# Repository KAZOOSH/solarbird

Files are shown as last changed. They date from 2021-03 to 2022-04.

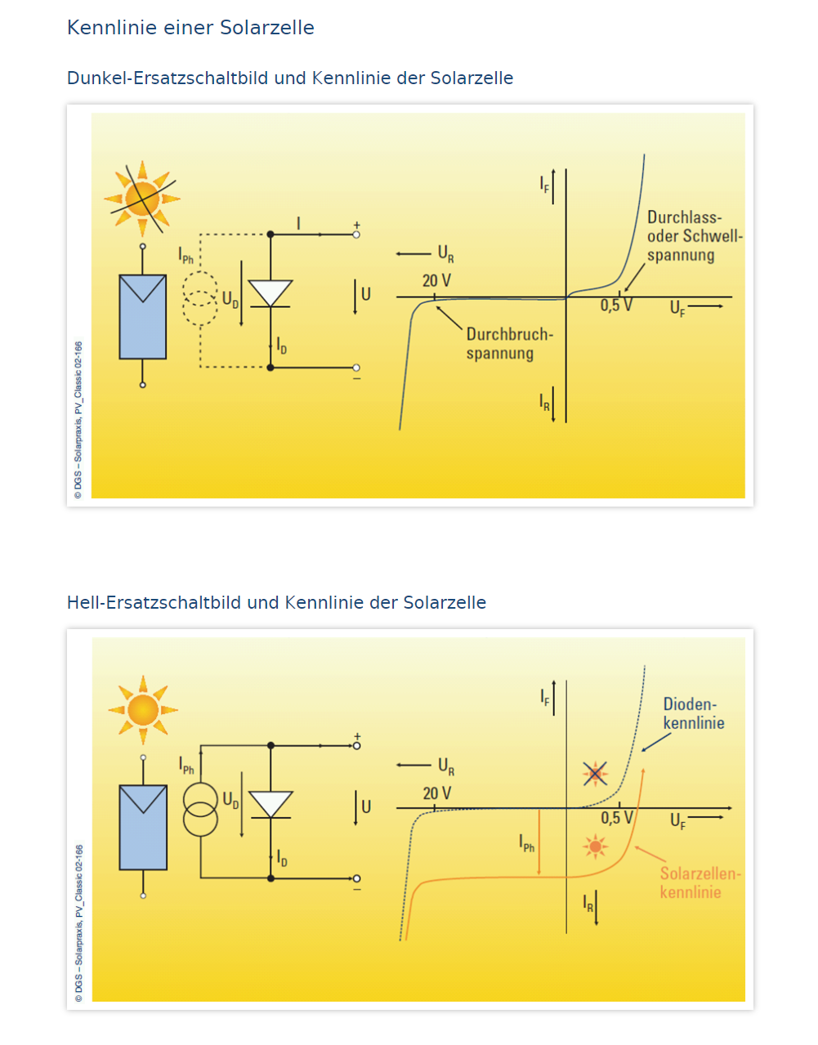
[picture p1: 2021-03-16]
material/Solarzelle_helldunkelkennlinie.png

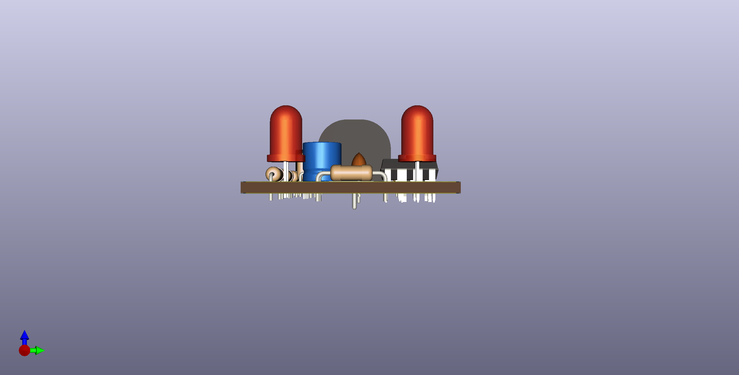
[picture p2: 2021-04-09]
pcb/Solaranimal_current pcb/board_t.png

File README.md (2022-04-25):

# Solarbird
Chirping birds with an ATtiny heart.

## How to flash SolarbirdTiny.ino with Arduino IDE

- Get an AVR ISP programmer or a spare Arduino and follow [these instructions](https://create.arduino.cc/projecthub/arjun/programming-attiny85-with-arduino-uno-afb829)
- Under Tools, select board “ATtiny25/45/85”, processor “ATtiny85”, and clock “Internal 8 MHz”
- Again under Tools, click Burn Bootloader (won't actually flash the Arduino bootloader but just set the fuses)
- Optional: change the code to include the bird voice of your choice (see following section)
- Flash the Arduino program as usual by clicking the Upload button

## How to change the bird's voice

At the time of writing, we have an imitation of a blackbird, a chiffchaff, a titmouse and a wren. Check the folder [voices](SolarbirdTiny/voices/) for all available bird voices.

In [SolarbirdTiny.ino near line 23](SolarbirdTiny/SolarbirdTiny.ino#L23), find the lines which include the bird voice and create a _Bird_ instance from it:
```c++
#include "voices/blackbird.h"
Blackbird Bird;
```

Change the name of the included file on the first line to the one of your liking. The code follows the convention that the class name (first word on the second line) is the capitalized version of the filename, i.e., the file `chiffchaff.h` contains the class `Chiffchaff`. After changing both lines, you're ready to upload the new voice to the ATtiny.

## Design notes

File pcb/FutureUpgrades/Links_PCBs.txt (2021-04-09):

pcb manufacturer tested with sharing options:

https://aisler.net/p/BBQTFBOA #####Germany Board V1.3 (add PROTO, remove 3.hole, add 2resistors for Akku state and mic bias)
https://oshpark.com/shared_projects/yvOFolXe #####Canada Board V1.31 ("After Dark" design)

pcb manufacturer also tested:
https://www.pcbway.com/ #####China
https://jlcpcb.com/ #####China

pcb manufacturer today not testet:
https://www.pcb-supermarkt.de/ #####Germany

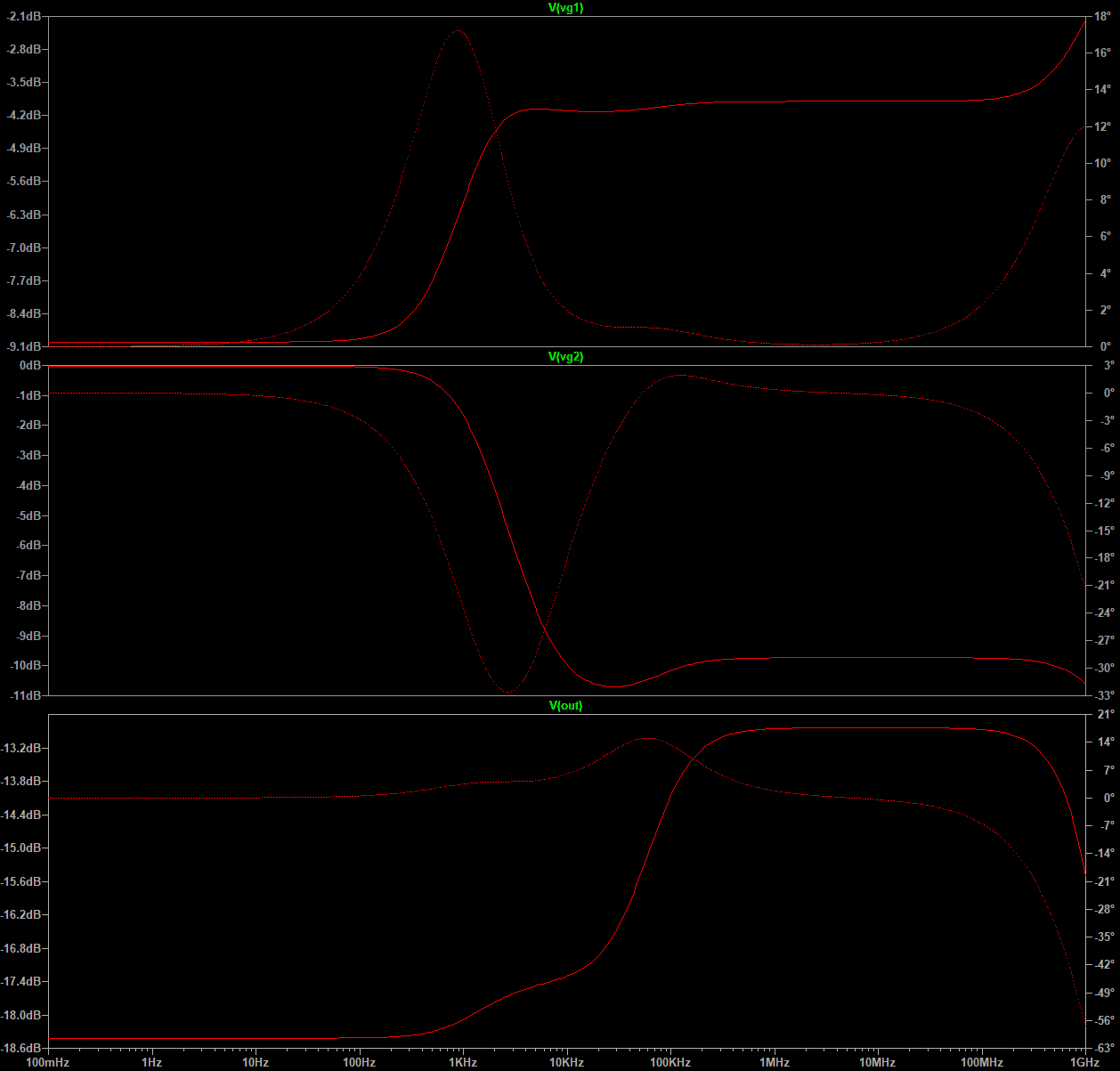
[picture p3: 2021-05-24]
circuit/spice/errorampAC.png

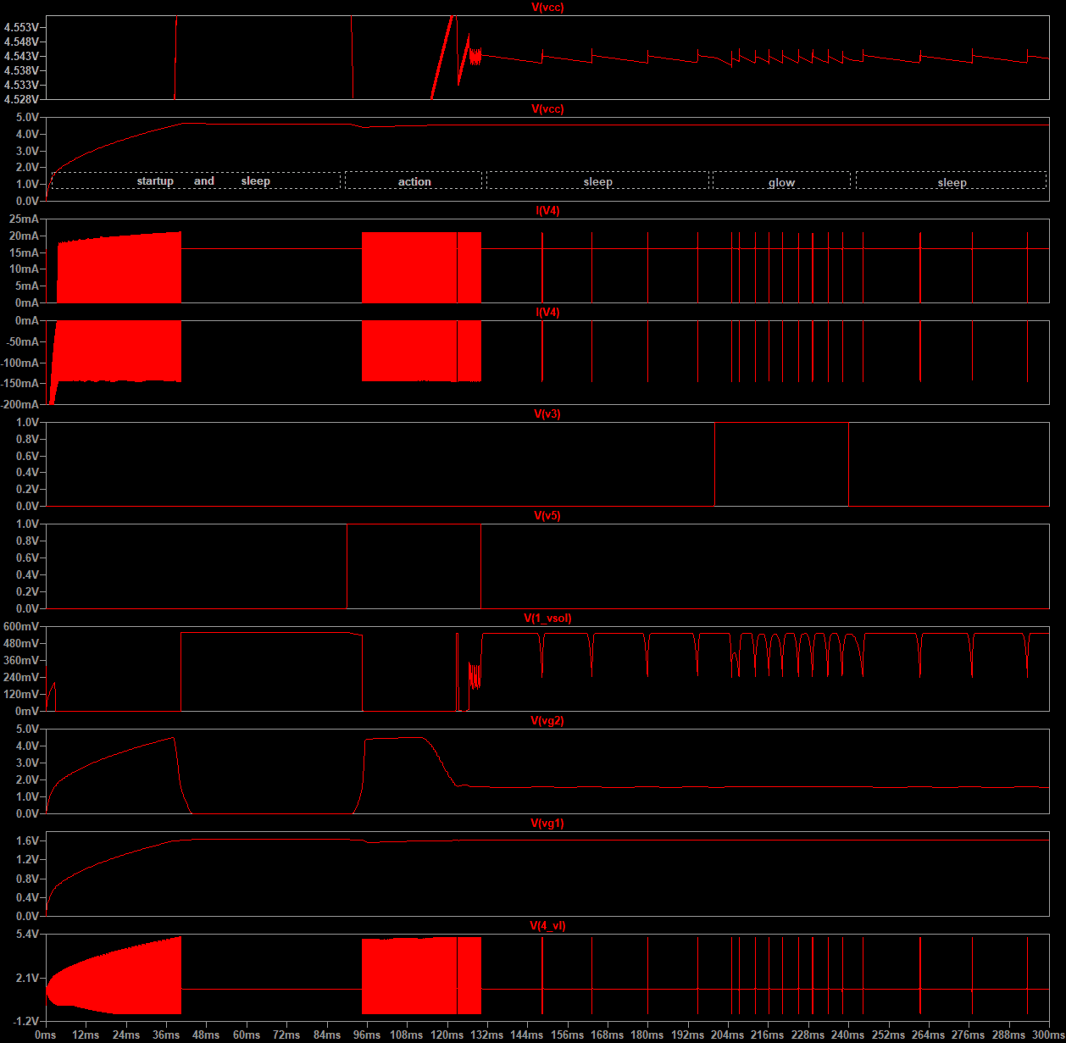
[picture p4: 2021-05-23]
circuit/spice/signals.png

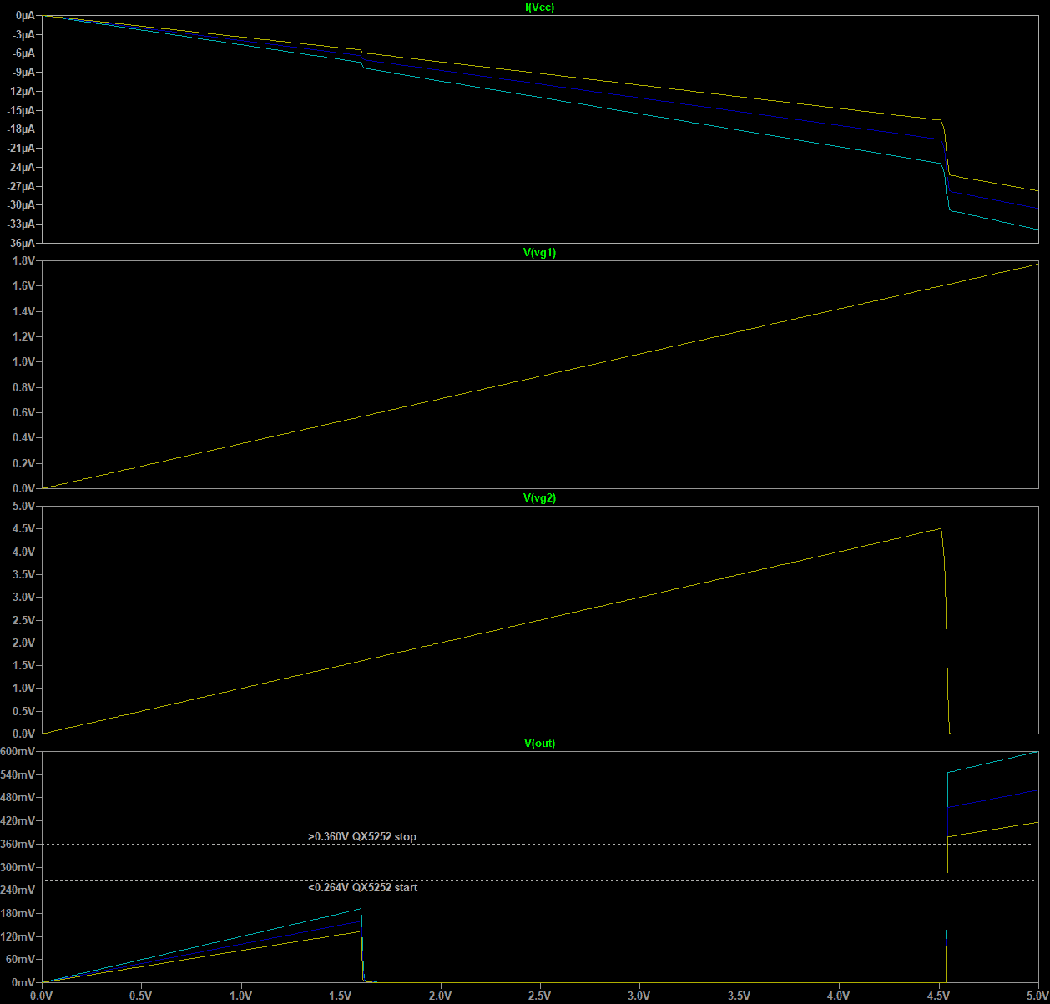
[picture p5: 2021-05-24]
circuit/spice/errorampDC.png

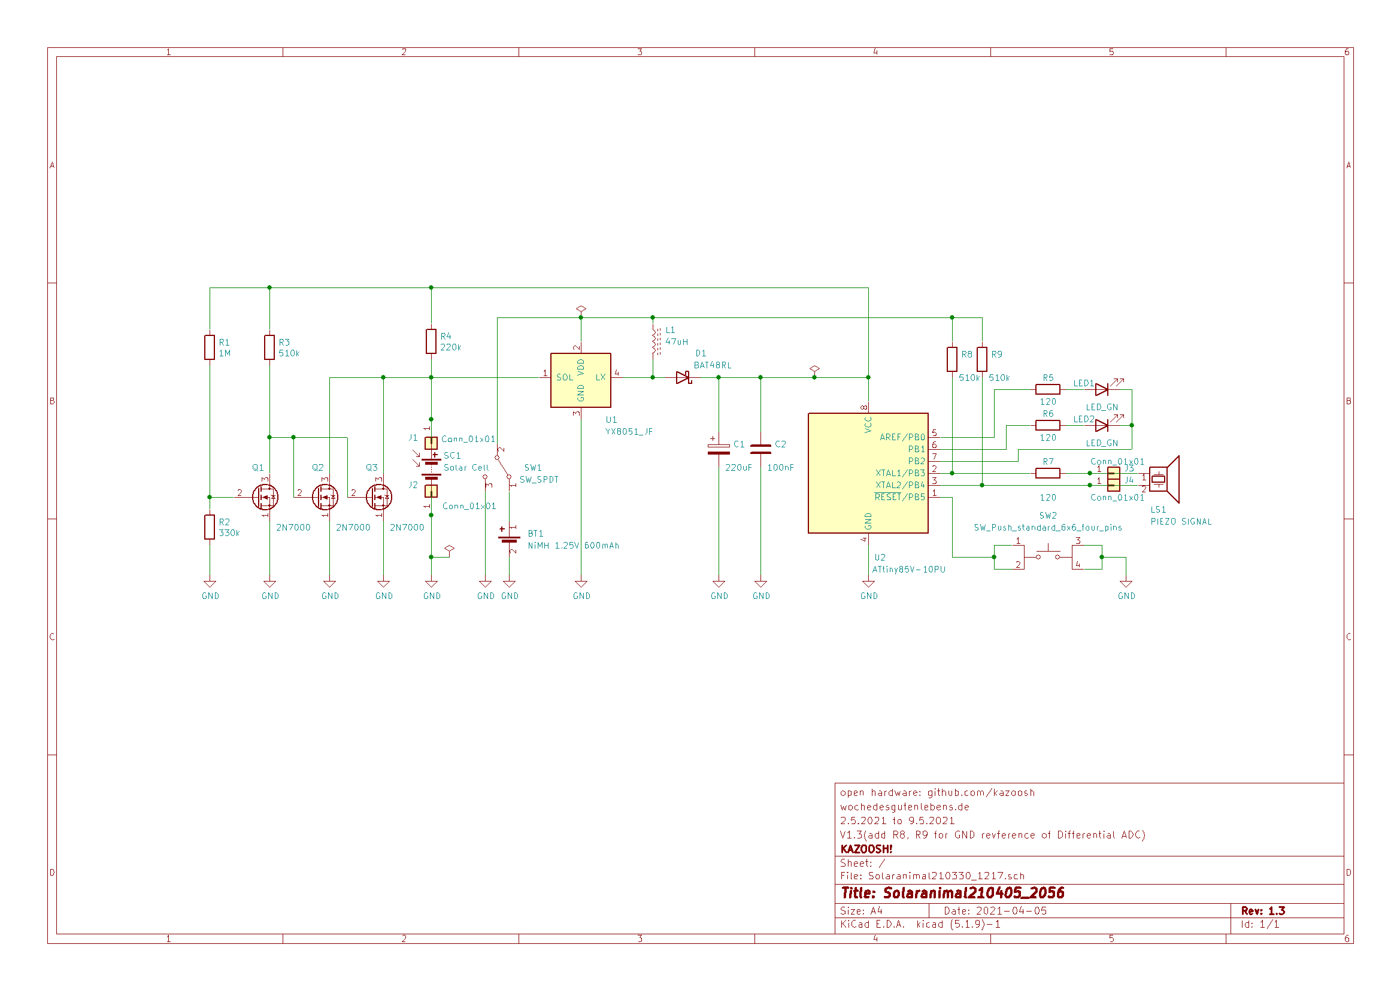
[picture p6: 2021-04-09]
pcb/FutureUpgrades/circuit.png

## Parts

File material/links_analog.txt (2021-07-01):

https://www.researchgate.net/publication/265036087_Analog_Front-End_Circuitry_in_Piezoelectric_and_Microphone_Detection_of_Photoacoustic_Signals
https://ww1.microchip.com/downloads/en/DeviceDoc/2N7000-N-Channel-Enhancement-Mode-Vertical-DMOS-FET-Data-Sheet-20005695A.pdf
https://simplifier.neocities.org/joule.html
https://www.tme.eu/de/details/ld-bzpn-2312/elektromagnetische-signalgeber-ohne-gen/loudity/ #####Piezo bei TME
https://www.onsemi.com/pdf/datasheet/mmbf170-d.pdf ##### BS170 Datasheed
http://schmidt-walter-schaltnetzteile.de/smps/smps.html #####Dimensionierung von Schaltnetzteilen
https://i.pinimg.com/originals/ae/01/0a/ae010a932937a33a02e720dccd400e55.jpg #####Farbcodes für Widerstände

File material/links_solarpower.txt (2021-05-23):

https://www.sciencetronics.com/greenphotons/?p=155
http://solarbotics.net/library/datasheets/sunceram.pdf
http://markbeck.de/elektronik.html
https://www.slideserve.com/urielle-clayton/photovoltaik
https://skootsone.yolasite.com/solar-led.php
http://www.elektronik-labor.de/Notizen/Solarlampen.html
https://www.elektronik-labor.de/Notizen/LEDwandler.html

https://datasheetspdf.com/datasheet/YX8051.html
https://oberguru.net/elektronik/led/step-up-wandler/qx5252/qx5252.html

https://www.electronicdeveloper.de/InduktivitaetSpeicherSNT.aspx ####Berechnung von Speicherdrosseln
https://www.tdk-electronics.tdk.com/download/528882/71e02c7b9384de1331b3f625ce4b2123/pdf-n87.pdf ####Kernmaterial N87
https://www.tdk-electronics.tdk.com/inf/80/db/fer/r_10_0_6_00_4_00.pdf ####Toroid core 10x6x4

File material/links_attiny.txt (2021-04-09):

https://ww1.microchip.com/downloads/en/DeviceDoc/Atmel-2586-AVR-8-bit-Microcontroller-ATtiny25-ATtiny45-ATtiny85_Datasheet.pdf
https://www.monsterli.ch/blog/elektronik/mikrocontroller/attiny25-attiny45-attiny85-sammelsurium/
http://www.technoblogy.com/show?QVN
http://www.technoblogy.com/show?QBB
http://www.technoblogy.com/show?ZU7
http://elm-chan.org/works/sd8p/report.html
http://elm-chan.org/works/sd20p/report.html
ADC App notes:
http://ww1.microchip.com/downloads/en/AppNotes/doc8003.pdf
http://ww1.microchip.com/downloads/en/Appnotes/atmel-8456-8-and-32-bit-avr-microcontrollers-avr127-understanding-adc-parameters_application-note.pdf
http://ww1.microchip.com/downloads/en/Appnotes/Atmel-2559-Characterization-and-Calibration-of-the-ADC-on-an-AVR_ApplicationNote_AVR120.pdf
https://microchipdeveloper.com/8avr:adcdiff
https://blog.podkalicki.com/100-projects-on-attiny13/
https://www.instructables.com/ElectronicKittyEars-Headset-DIY/ #####DIY Programmer for Kittys

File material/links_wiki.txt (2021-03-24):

210323:
https://docs.google.com/spreadsheets/d/1iGpreHylvdMuwipeQVSpeXQ6AU2KrBsxj3lGD7Qvc1k/edit?usp=sharing

https://www.youtube.com/watch?v=KNeW3BZsALQ

https://raw.githubusercontent.com/badgeek/svg2shenzhen/master/doc/resources/showcase.jpeg

https://pcbshopper.com/

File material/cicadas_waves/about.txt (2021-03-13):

timecode: xxx:xx:ms
stereo in 1
sampling rate 44100Hz

source: Der Sound des Sommers... .mp3

the envelope of cicadas sounds is about 110ms to 160ms
sound is about 50% of the envelope
base frequency is about 5500Hz
there are 3ms ripples in the amplitude of base frequency

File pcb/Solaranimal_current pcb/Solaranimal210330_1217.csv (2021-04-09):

Id | Designator | Package | Quantity | Designation | Supplier and ref
1 | Q2 | TO-92_Inline_Wide | 1 | ZVN4206AVSTZ
2 | G*** | Kazoosh!-Logo | 1 | LOGO
3 | M3 | MountingHole_3.2mm_M3_Pad_TopBottom | 1 | MountingHole_3.2mm_M3_Pad_TopBottom
4 | SW2 | SW_PUSH_6mm_H5mm_4pin | 1 | SW_Push_standard_6x6_four_pins
5 | U2 | DIP-8_W7.62mm | 1 | ATtiny85V-10PU
6 | U1 | R_Array_SIP4 | 1 | YX8051_JF
7 | SW1 | SW_Slide_1P2T_CK_OS102011MS2Q | 1 | SW_SPDT
8 | R7,R6,R5 | R_Axial_DIN0207_L6.3mm_D2.5mm_P10.16mm_Horizontal | 3 | 120
9 | R4 | R_Axial_DIN0207_L6.3mm_D2.5mm_P10.16mm_Horizontal | 1 | 220k
10 | R3 | R_Axial_DIN0207_L6.3mm_D2.5mm_P10.16mm_Horizontal | 1 | 510k
11 | R2 | R_Axial_DIN0207_L6.3mm_D2.5mm_P10.16mm_Horizontal | 1 | 330k
12 | R1 | R_Axial_DIN0207_L6.3mm_D2.5mm_P10.16mm_Horizontal | 1 | 1M
13 | Q1 | TO-92_Inline_Wide | 1 | 2N7000
14 | LED2,LED1 | LED_D5.0mm | 2 | LED_GN
15 | L1 | R_Axial_DIN0207_L6.3mm_D2.5mm_P10.16mm_Horizontal | 1 | 47uH
16 | J4,J3,J2,J1 | SolderWire-0.5sqmm_1x01_D0.9mm_OD2.1mm_Relief | 4 | Conn_01x01
17 | D1 | D_DO-35_SOD27_P10.16mm_Horizontal | 1 | BAT48RL
18 | C2 | C_Disc_D4.7mm_W2.5mm_P5.00mm | 1 | 100nF
19 | C1 | CP_Radial_D6.3mm_P2.50mm | 1 | 220uF
20 | BT1 | BatteryHolder_Keystone_2466_1xAAA | 1 | NiMH 1,25V 600mAh

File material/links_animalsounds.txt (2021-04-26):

https://www.podcast.de/episode/367164861/Zikaden+-+Der+Sound+des+Sommers/
https://stackoverflow.com/questions/16891655/galois-lfsr-explanation-of-code

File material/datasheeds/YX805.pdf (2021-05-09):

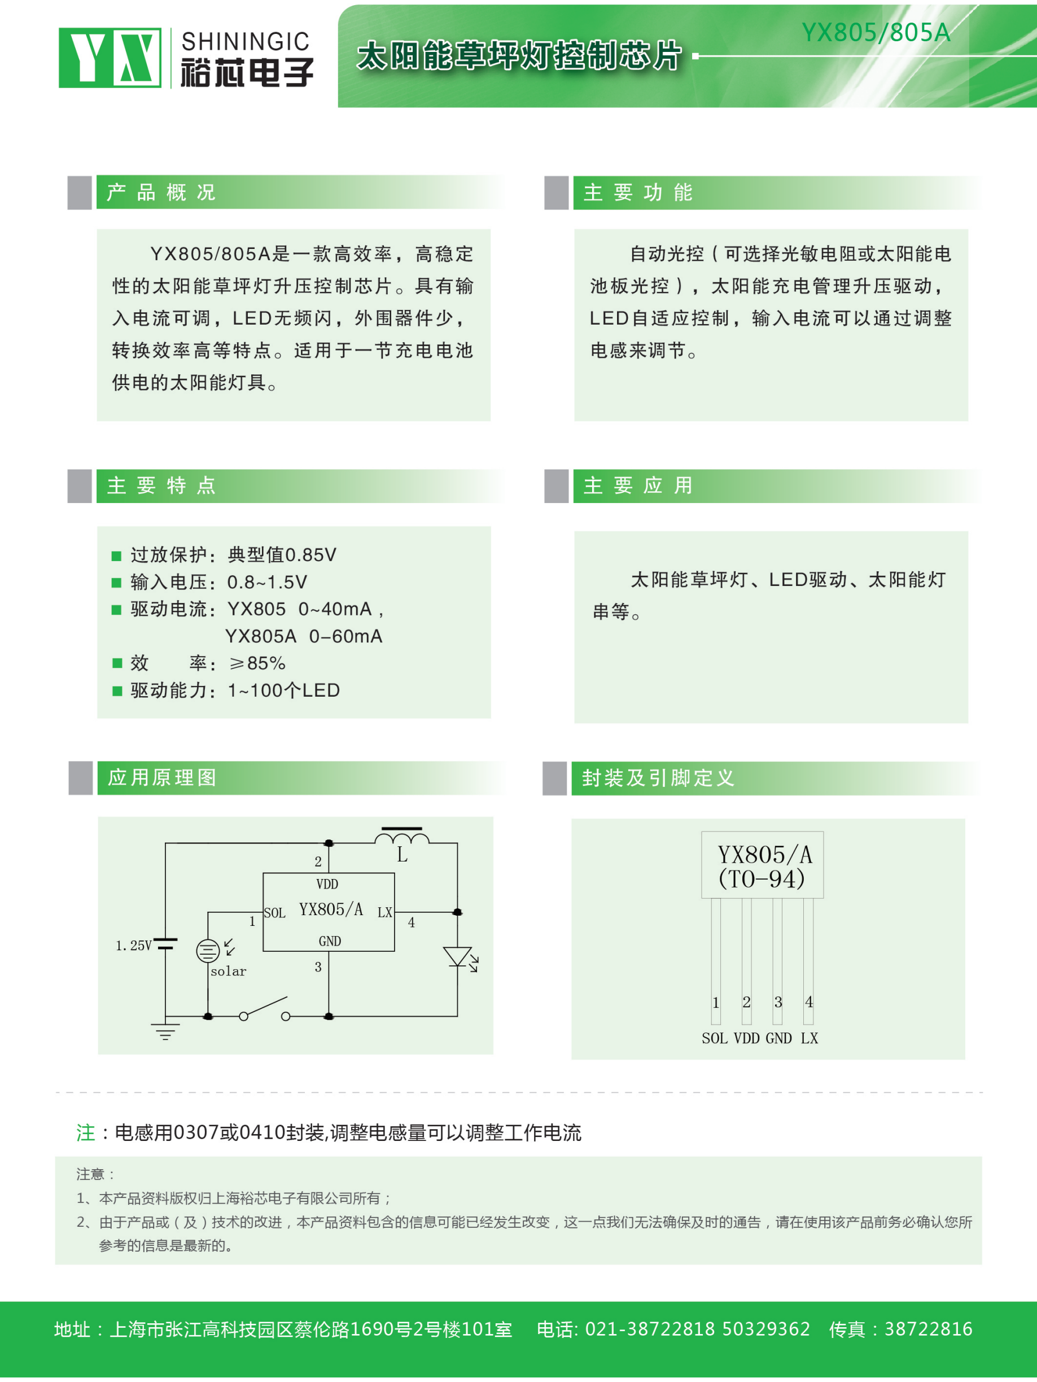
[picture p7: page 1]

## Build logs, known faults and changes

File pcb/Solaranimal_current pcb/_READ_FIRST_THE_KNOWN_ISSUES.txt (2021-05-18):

1.) wrong footprint connection of sw2 (1 and 3 are shorted. 2 and 4 are shorted.)
--> fix: cutting 2 diagonal pins after soldering the other 2 pins.

2.) Vcc is too high 
--> fix: change R2 from 330k to 650k because Vgth of Q1 in our new pool is 1.7V (before in first prototypes Vgth=1.0V) Vcc should be ca. 4.4V

3.) footprint of Q2 has wrong direction because we use now an different mosfet as Q2 (tn0604 or ZVN4206 are the better ones, BS170 the older one)
--> fix: Q2 (tn0604 or ZVN4206) is mounted like Q1

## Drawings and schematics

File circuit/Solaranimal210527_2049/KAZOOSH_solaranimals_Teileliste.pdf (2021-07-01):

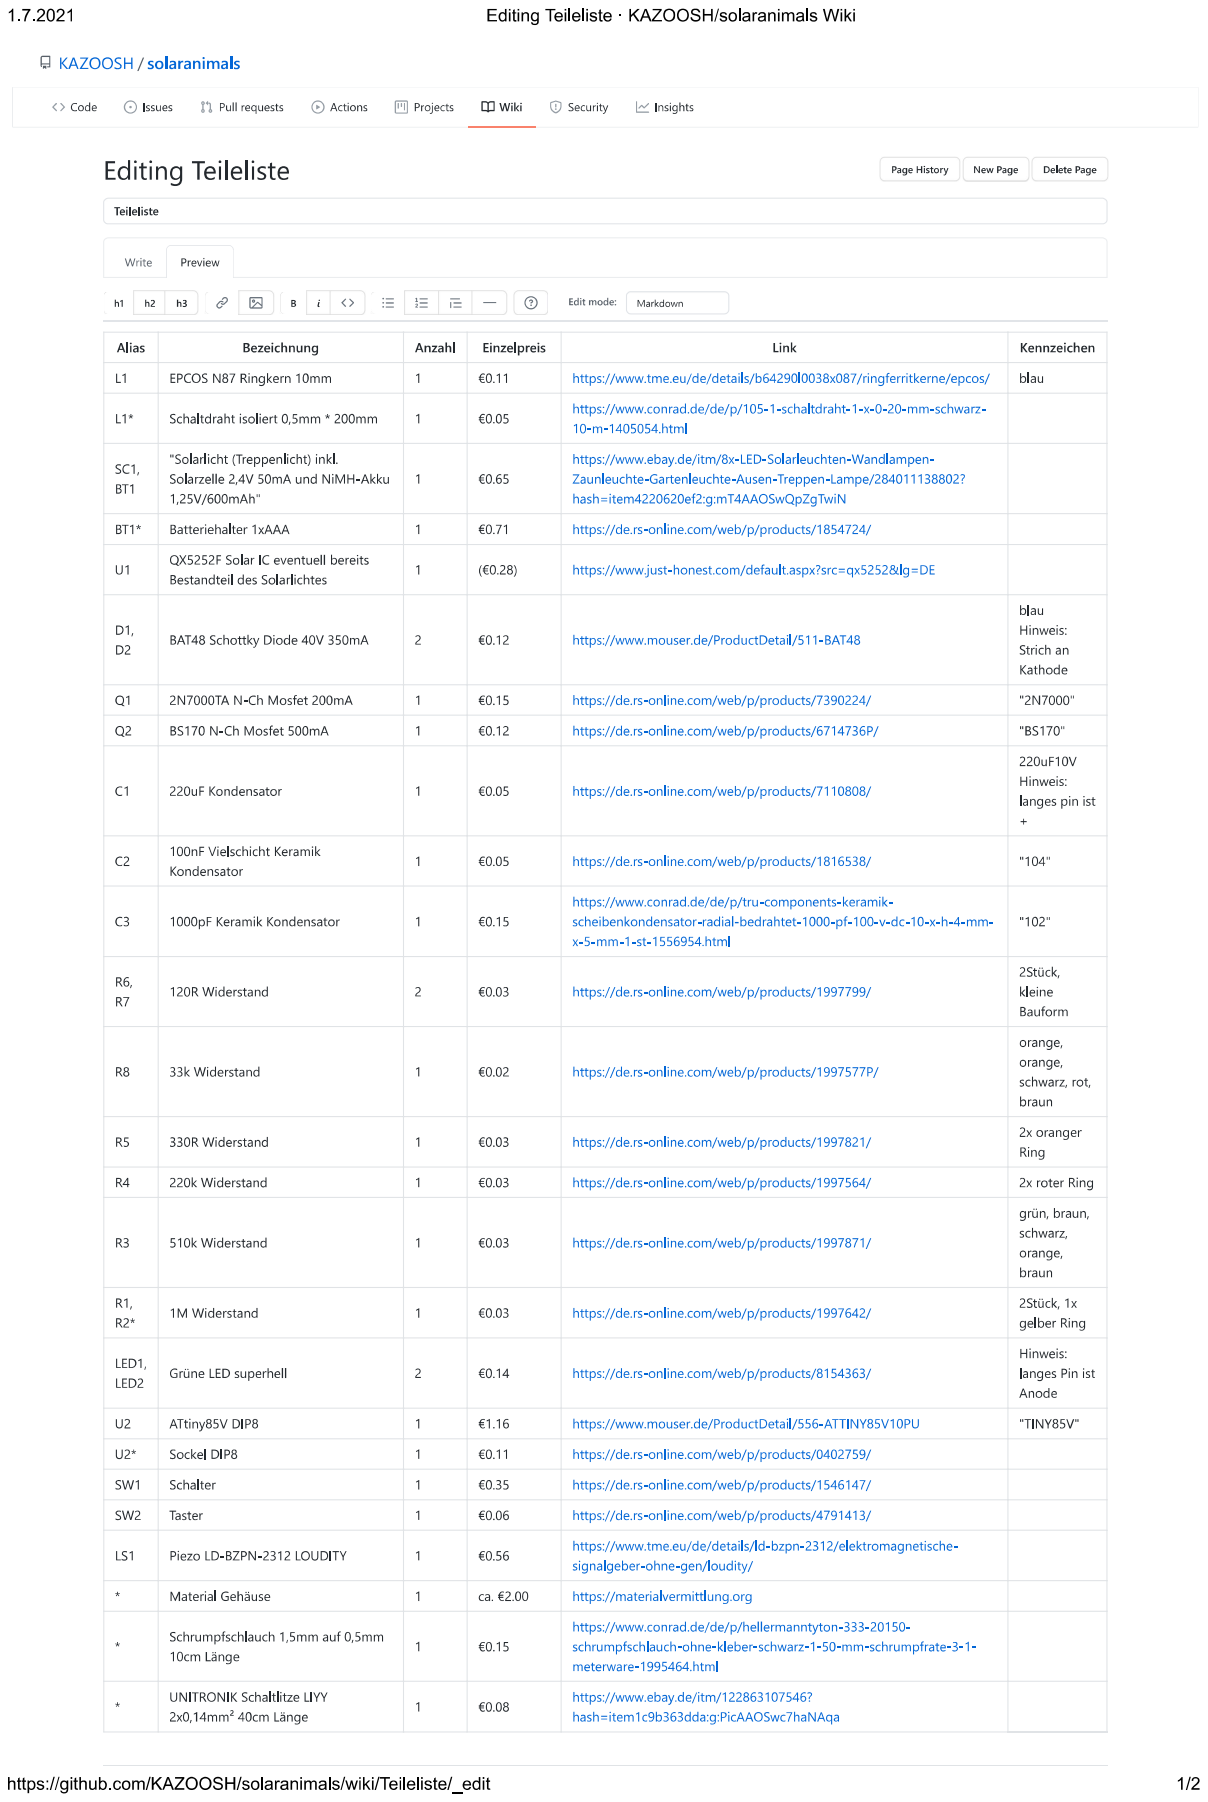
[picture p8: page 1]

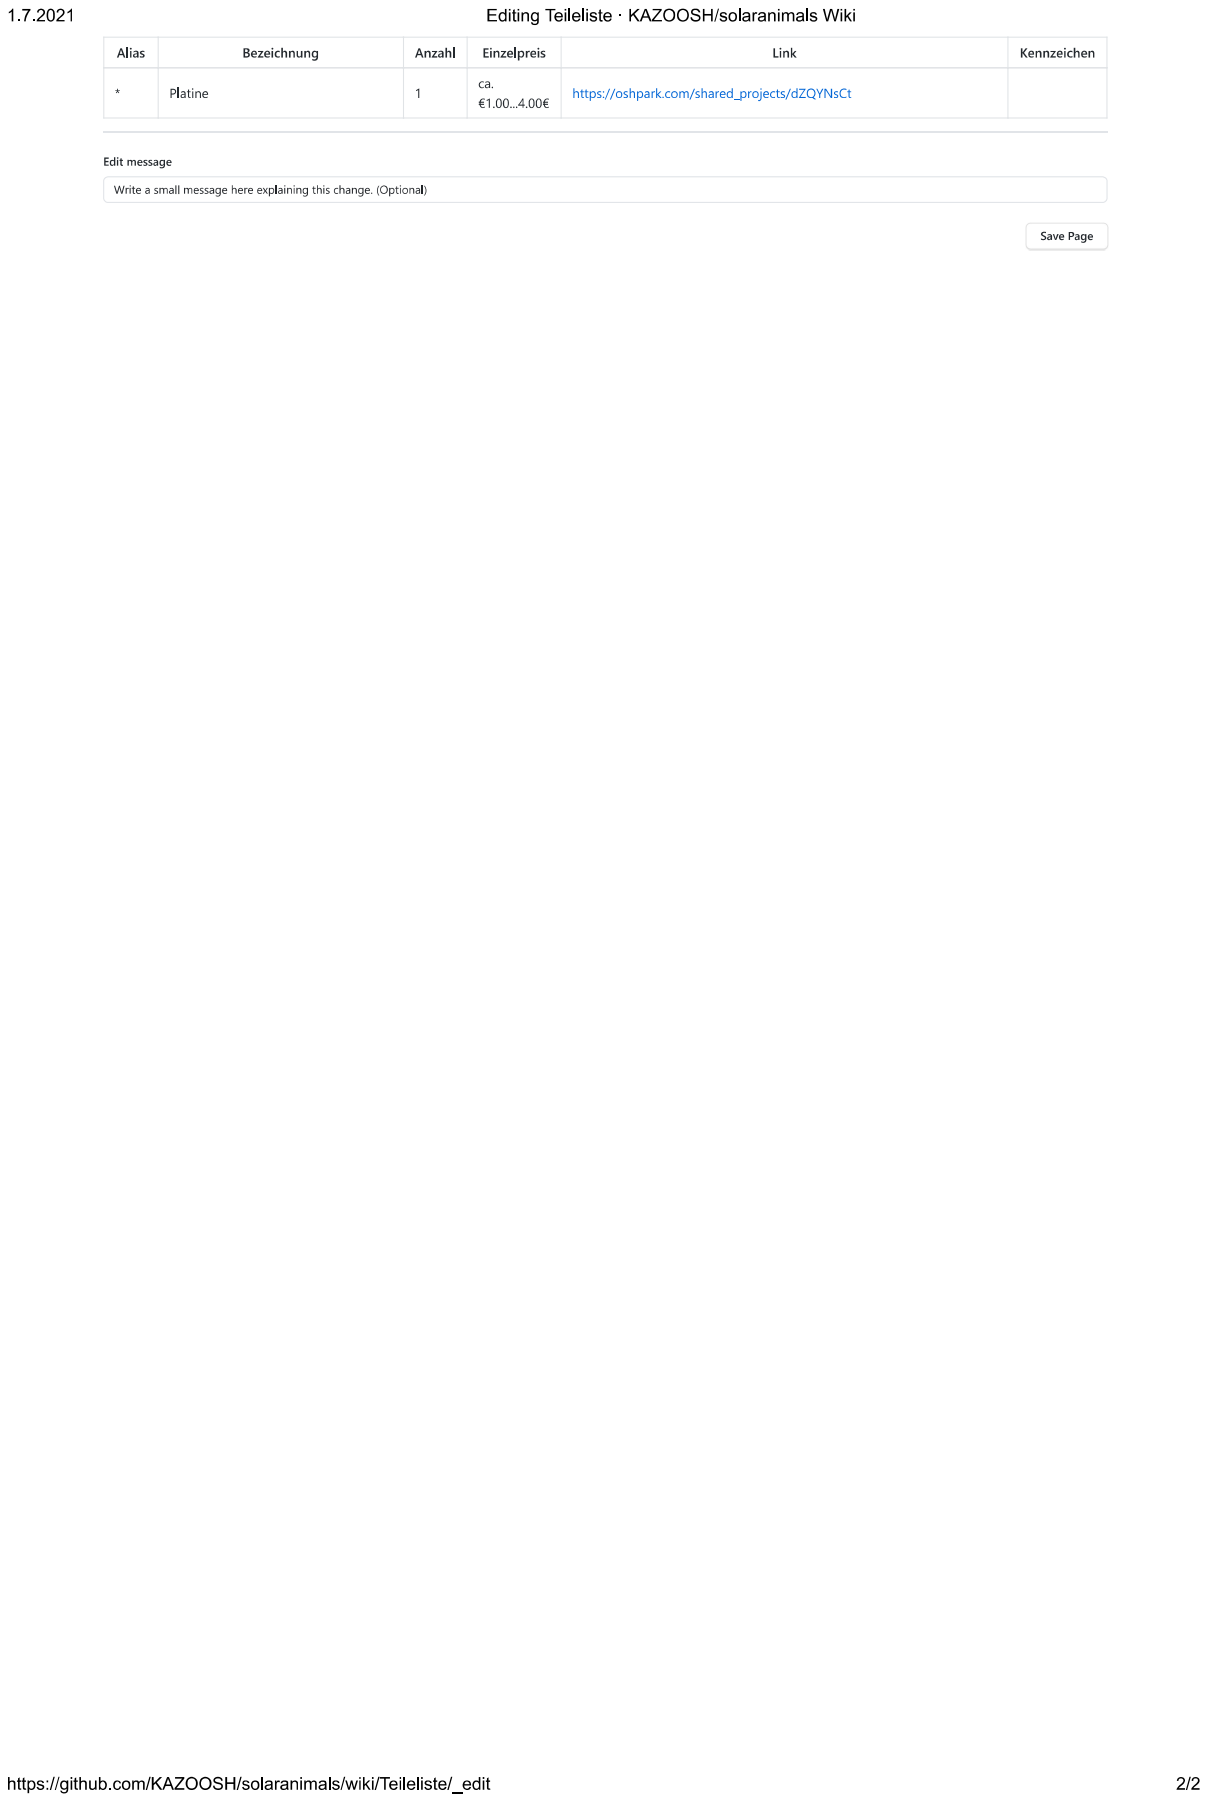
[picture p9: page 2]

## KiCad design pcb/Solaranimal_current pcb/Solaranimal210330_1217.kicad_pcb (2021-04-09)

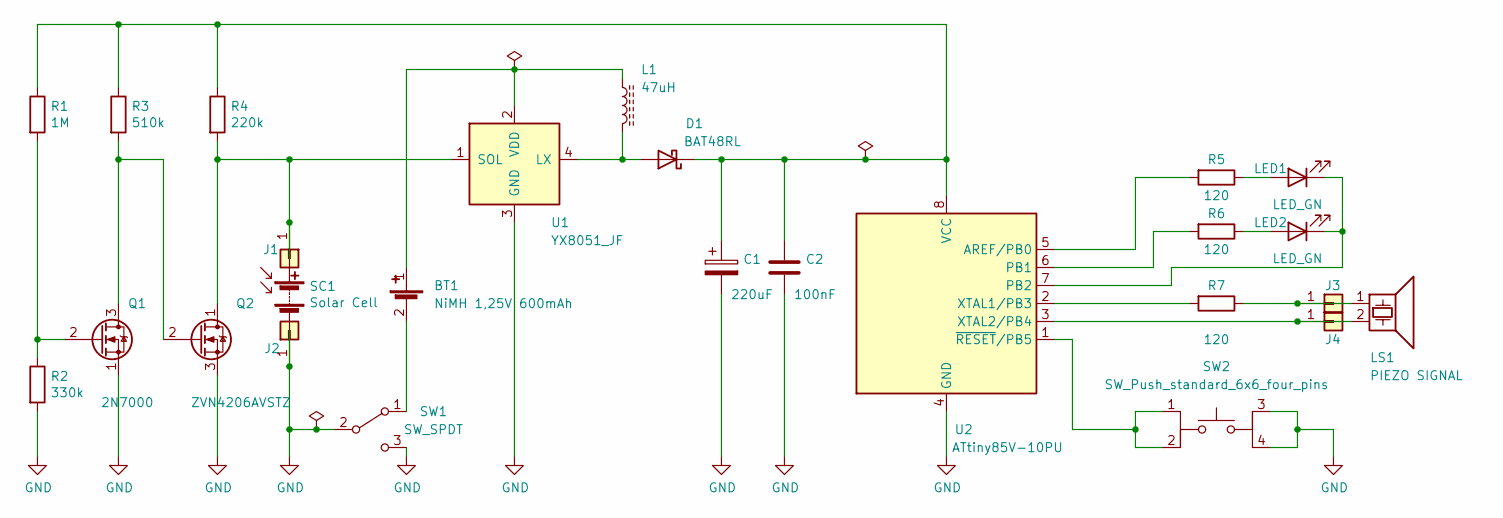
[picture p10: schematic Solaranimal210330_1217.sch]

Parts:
BT1: NiMH 1,25V 600mAh; BatteryHolder_Keystone_2466_1xAAA
C1: 220uF; CP_Radial_D6.3mm_P2.50mm
C2: 100nF; C_Disc_D4.7mm_W2.5mm_P5.00mm
D1: BAT48RL; D_DO-35_SOD27_P10.16mm_Horizontal
J1, J2, J3, J4: Conn_01x01; SolderWire-0.5sqmm_1x01_D0.9mm_OD2.1mm_Relief
L1: 47uH; R_Axial_DIN0207_L6.3mm_D2.5mm_P10.16mm_Horizontal
LED1, LED2: LED_GN; LED_D5.0mm
LS1: PIEZO SIGNAL
Q1: 2N7000; TO-92_Inline_Wide
Q2: ZVN4206AVSTZ; TO-92_Inline_Wide
R1: 1M; R_Axial_DIN0207_L6.3mm_D2.5mm_P10.16mm_Horizontal
R2: 330k; R_Axial_DIN0207_L6.3mm_D2.5mm_P10.16mm_Horizontal
R3: 510k; R_Axial_DIN0207_L6.3mm_D2.5mm_P10.16mm_Horizontal
R4: 220k; R_Axial_DIN0207_L6.3mm_D2.5mm_P10.16mm_Horizontal
R5, R6, R7: 120; R_Axial_DIN0207_L6.3mm_D2.5mm_P10.16mm_Horizontal
SC1: Solar Cell
SW1: SW_SPDT; SW_Slide_1P2T_CK_OS102011MS2Q
SW2: SW_Push_standard_6x6_four_pins; SW_PUSH_6mm_H5mm_4pin
U1: YX8051_JF; R_Array_SIP4
U2: ATtiny85V-10PU; DIP-8_W7.62mm

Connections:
GND: C1.2, C2.2, J2.1, Q1.1 (S), Q2.3 (S), R2.2, SC1.2 (-), SW1.2 (B), SW1.3 (C), SW2.3, SW2.4, U1.3 (GND), U2.4 (GND)
unnamed: BT1.1 (-), L1.1, U1.2 (VDD)
unnamed: BT1.2 (plus), SW1.1 (A)
unnamed: C1.1, C2.1, D1.1 (K), R1.1, R3.1, R4.1, U2.8 (VCC)
unnamed: D1.2 (A), L1.2, U1.4 (LX)
unnamed: J1.1, Q2.1 (D), R4.2, SC1.1 (+), U1.1 (SOL)
unnamed: J3.1, LS1.1, R7.1
unnamed: J4.1, LS1.2, U2.3 (XTAL2/PB4)
unnamed: LED1.1 (K), LED2.1 (K), U2.7 (PB2)
unnamed: LED1.2 (A), R5.1
unnamed: LED2.2 (A), R6.1
unnamed: Q1.2 (G), R1.2, R2.1
unnamed: Q1.3 (D), Q2.2 (G), R3.2
unnamed: R5.2, U2.5 (AREF/PB0)
unnamed: R6.2, U2.6 (PB1)
unnamed: R7.2, U2.2 (XTAL1/PB3)
unnamed: SW2.1, SW2.2, U2.1 (~RESET~/PB5)

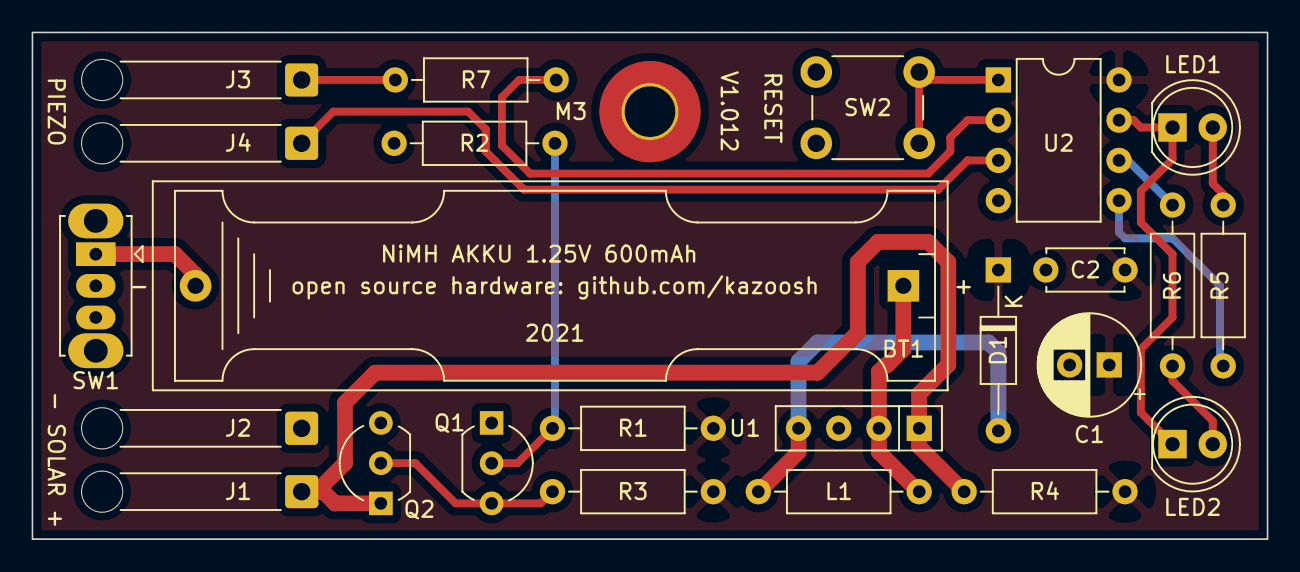
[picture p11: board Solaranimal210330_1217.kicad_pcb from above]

Board: 2 copper layers, 78.0 x 32.0 mm, 25 parts (0 on the bottom side), 17 nets.

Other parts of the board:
M3: MountingHole_3.2mm_M3_Pad_TopBottom

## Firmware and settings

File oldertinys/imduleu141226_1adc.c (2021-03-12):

/*
 *   _               _       _           __ _  _  __ ___  ___   __  __           _      
 *  (_)             | |     | |         /_ | || |/_ |__ \|__ \ / / /_ |         | |     
 *   _ _ __ ___   __| |_   _| | ___ _   _| | || |_| |  ) |  ) / /_  | | __ _  __| | ___ 
 *  | | '_ ` _ \ / _` | | | | |/ _ \ | | | |__   _| | / /  / / '_ \ | |/ _` |/ _` |/ __|
 *  | | | | | | | (_| | |_| | |  __/ |_| | |  | | | |/ /_ / /| (_) || | (_| | (_| | (__ 
 *  |_|_| |_| |_|\__,_|\__,_|_|\___|\__,_|_|  |_| |_|____|____\___/ |_|\__,_|\__,_|\___|
 *                                                              ______                  
 *                                                             |______|      
 * imdueu141226_1adc.c
 * Created: 26.12.2014 17:21:15
 * Author: Johannes
 * Version: 1.1adc (status working, adc working)
 * Lizenz: one coffee two persons one dog
 * Hardware: ATtiny45
 * Fuses: lfuse=F3, hfuse=DF, efuse=FF
 *
 * EIN HUNDEHALSBAND    
 *                                                     |       ___
 *                      .--------------------------o---| |----|___|------.
 *                      |                          |   |                 |
 *                      |                          | 3.6V     3.6R       |
 *                      |    .----###----.         | LI-Cell  safety     |
 *      4*100R          '----o RST   VCC o---------o                     |
 *       ___   LED           |           |         |                     |
 *   .--|___|--|<--o------o--o ADC3  SCK o------.  |          4*100R     |
 *   |   ___   LED |      |  |           |      |  |     LED   ___       |
 *   o--|___|--|<--'   .--)--o ADC2 MISO o------)--)--o-->|---|___|------o
 *   |                 |  |  |           |      |  |  |  LED   ___       |
 *   o-----------------)--)--o GND  MOSI o -.   |  |  '-->|---|___|------o
 *   |                 |  |  '-----------'  |   |  |                     |
 *   |   ___   LED     |  |                 |   |  |     LED   ___       |
 *   o--|___|--|<------o  |    ATtiny45     |   |  |  .-->|---|___|------o
 *   |   ___   LED     |  |                 |   |  |  |  LED   ___       |
 *   o--|___|--|<------o  |                 '---)--)--o-->|---|___|------o
 *   |                 |  |                     |  |                     |
 *   |        ___      |  |                     |  |                     |
 *   |  .----|___|-----'  |         .-----------'  o-----.               |
 *   |  |     LDR         |         |              |     |               |
 *   |  '-----------------'       | o             ###   ###              |
 *   |                          |=|>              ---   ---   2*220uF    |
 *   |                            | o              |     |               |
 *   |                              |              |     |               |
 *   |                              |              |     |               |
 *   '------------------------------o--------------o-----o---------------'
 *
 */

#define F_CPU 6400000UL
//#define PICOPOWER uncomment if AVR can disable Brown-out by software during sleep 
// (else comment + disable BOD by fuse)

// Pins ATtiny 25,45,85 (13, 13A different INT0-Pin)
#define MOSI 0 //PB0                Pin5 ISP_input
#define MISO 1 //PB1 (t13 INT0)     Pin6 ISP_output
#define SCK 2  //PB2 INT0!          Pin7 ISP_input
#define ADC3 3 //PB3                Pin2 GPIO
#define ADC2 4 //PB4                Pin3 GPIO
//    !RESET   PB5(disabled)        Pin1 RESET
//    VCC                           Pin8
//    GND                           Pin4

//#define LEDS (1<<MISO)
#define LEDS ((1<<MOSI)|(1<<MISO)|(1<<ADC3)|(1<<ADC2))
#define TASTE (1<<SCK)
#define LEDS_ON   (PORTB |=  LEDS)
#define LEDS_OFF  (PORTB &= ~LEDS)
#define LEDS_TOGGLE (PINB |= LEDS)
#define TASTE_OFF   (PINB & TASTE)
#define TASTE_ON    (~TASTE_OFF)

// 12h EINSCHALTDAUER
#define ONCNTDOWN   (3600000UL*12)/(32*120)
// ALTERNATIV 1min EINSCHALTDAUER (TESTMODE)
//#define ONCNTDOWN (3600000UL/60)/(32*120) 

// Libs
#include <avr/io.h> 
#include <util/delay.h>
#include <avr/sleep.h>
#include <avr/interrupt.h>
#include <avr/wdt.h>

// Global Variables
volatile uint8_t state=0;                           // STATUS HALSBAND: 0=OFF;1...0xFE=COUNTDOWN;0xFF=ON
volatile uint8_t wdtcnt=0;                          // ZÄHLER FÜR WECKZYKLEN
volatile uint32_t oncntdown = ONCNTDOWN;            // ZÄHLER FÜR EINSCHALTDAUER
uint8_t dark=0;                                     // WENNS DUNKEL IST, WIRDS 1

// Funktions
void init_adc()                         // VORBEREITUNG AD-WANDLUNG LICHTSENSOR
{
    ADCSRA |= (1<<ADPS0)|(1<<ADPS2);    // ADC prescaler = 32 (6,4M/32=200k), Voltage ref. Vcc 3V(is default)
}

void prepareLDR()                       // VORBEREITUNG LICHTMESSUNG
{
    // LDRPWR via pullup(40k) on Vcc 
    cli();
    DDRB  &= ~(1<<ADC2);                // LICHTSENSOR HOTPIN ALS EINGANG
    PORTB |=  (1<<ADC2);                // LICHTSENSOR MESSTROM AN
    //PORTB &= ~(1<<ADC3);              // LICHTSENSOR COLDPIN AN 0V SCHON ERLEDIGT
    _delay_ms(5);
    sei();  
}

void deactivateLDR()                    // ZUSTAND WIE VOR LICHTMESSUNG
{ 
    cli();
    DDRB  |=  (1<<ADC2);                // LICHTSENSORPIN WIEDER ALS AUSGANG
    PORTB &= ~(1<<ADC2);                // STROM AUS
    ADCSRA &= ~(1<<ADEN);               // AD-WANDLER AUS
    sei();  
}

uint16_t readADC(uint8_t smooth)
{
    cli();
    prepareLDR();
    ADCSRA |= (1<<ADEN);                // AD-WANDLER EINSCHALTEN STROMVERBRAUCH 200 MIKROAMPERE
    //ADMUX  = (1<<MUX1);               // ADC2 (PB4, Pin3) INPUT, Vcc as Reference
    ADMUX  = (1<<MUX2)|(1<<MUX1);       // ADC3 (PB3, Pin2) -EINGANG ADC2 (PB4, Pin3) +EINGANG Vcc IST REFERENZWERT
    ADCSRA |= (1<<ADSC);                // dummyconversion 25 ADC-clocks
    while(ADCSRA & (1<<ADSC));          // wait for finishing AD-conversion
   (void) ADCW;                         // ADC-readout to void

    uint16_t temp = 0;
    uint8_t i = smooth;
    while(i)
    {
        i--;
        ADCSRA |= (1<<ADSC);            // START AD-WANDLUNG
        while(ADCSRA&(1<<ADSC));        // waiting for end of conversion, duration 13ADC-clocks
        //low = ADCL;                   // first reading (locking of ADCH)
        //high = ADCH;                  // later get ADCH
        //temp += ((high<<8) | low); 
        temp += ADCW;                   // summary 10bit ADC-readouts, ADCW is C-compiler 16-bit pseudo-register 
    }
    deactivateLDR();
    sei();    
    return(temp / smooth);              // RÜCKGABE DES MITTELWERTS DER AD-WANDLUNGEN VON HELLIGKEITSMESSUNG
}

void goes_power_down_now()
{
    cli();
    set_sleep_mode(SLEEP_MODE_PWR_DOWN);
    #if defined (PICOPOWER)
    sleep_bod_disable(); // timed: disable brown-out during sleep (for ATtiny85 at Rev. C or newer) ***page35,149
    #endif
    sei();
    sleep_mode();
}

void init_ports()                               // TASTENSTROM AN, LEDPINS ALS AUSGANG
{
    DDRB  |=  LEDS;
    LEDS_OFF;
    PORTB |= TASTE;
}

void init_pininterrupts()                       // WECKEN DURCH TASTE MÖGLICH
{
    GIMSK  |=  (1<<INT0);
}

void no_pininterrupts()                         // WECKEN DURCH TASTE UNMÖGLICH
{
    GIMSK  &=  ~(1<<INT0);
}

void init_wdt(uint8_t wdtcrTimeBits) // START TIMER, STROMVERBRAUCH 6 MIKROAMPRE 
{
    cli();
    // clear WDT interrupt flag
    MCUSR &= ~(1<<WDRF);
    // allow changes, enable WDT not used on safety level1 (no WDTON-fuse programmed)
    // WDTCR = (1<<WDCE) | (1<<WDE);
    // WDT and WDT interrupt enable: set WDE, WDIE, delaytime to wakeup
    WDTCR = (1<<WDIE) | (1<<WDE) | wdtcrTimeBits;
    wdt_reset();
    sei();
}

void wdt_off()                       // STOP TIMER: WECKEN DURCH TIMER UNMÖGLICH STROMVERBRAUCH 0,1 MIKROAMPRE
{
    wdt_reset();
    // Clear WDR Flag in MCUSR
    MCUSR &= ~(1<<WDRF);
    // Write logical one to WDCE and WDE allow disable WDT in booth safety levels
    WDTCR |= (1<<WDCE) | (1<<WDE);
    // Turn off WDT
    WDTCR = 0;
}

void flashLEDS()                     // LEDS BLITZEN STROMVERBRAUCH MAXIMAL 80 MILLIAMPERE
{
    cli();
    if(state)
    {
        LEDS_ON;
        _delay_us(30);
        if((state == 0xFF) && dark)
        {
            if     (wdtcnt==30) _delay_ms(3);
            else if(wdtcnt==31) _delay_ms(10);
        }
        LEDS_OFF;
    }
    sei();
}

// Interupts
ISR(WDT_vect)                                   // DURCH TIMER GEWECKT
{
    cli();
    wdt_off();
    if(TASTE_OFF)
    {
        init_pininterrupts();
        if(state && oncntdown)                  // HALSBAND EIN
        {
            state=0xFF;
            init_wdt(WDTO_120MS);
            if(wdtcnt==31) oncntdown--; 
        }
        else                                    // HALSBAND AUS
        {
            oncntdown = ONCNTDOWN;
            state=0;
        }
    }
    else                                        // TASTE NOCH GEDRÜCKT, COUNTDOWN BIS AUS
    {
        if(state)state--;
        init_wdt(WDTO_15MS);
    }
    wdtcnt++;                                   // ALLE ACHTUNG DU HAST DAS HIER GELESEN??
    if(wdtcnt>=32) wdtcnt=0;                    // DANN KOMM ICH DAS NÄCHSTE MAL MIT KLETTERN (HAB SCHUHE)
    sei();
}

ISR(INT0_vect)                                  // DURCH TASTE GEWECKT
{
    cli();
    no_pininterrupts();
    init_wdt(WDTO_15MS);
    state--;
    sei();
}

// main (init, sleeping and LEDS)
int main(void)
{
    cli();                                       // MIKROCONTROLLER BOOTET ;-)                     
    wdt_off();
    init_ports();
    init_adc();
    init_pininterrupts(); 
    sei();
    while(1)                              
    { 
        if((wdtcnt==29) && TASTE_OFF) dark=(readADC(8U)>600);
        flashLEDS();                            // MIKROCONTROLLER ARBEITET :-(
        goes_power_down_now();                  // MIKROCONTROLLER TRÄUMT SÜSS B-)
    }
}


/*
 * Aus der Ferne und wenns ganz dunkel ist könnte man den Hund jetzt auch für ne Boeing747
 * auf dem Rollfeld halten. Das hab ich nicht beabsichtigt. Und ich hab paar Kommentare extra auf
 * Deutsch geschrieben, damit Du mit dem Lesen bis hier unten durchhältst.
 * Und jetzt häng ich nochn paar Sternchen dran:   
 *                                                                                |    
 *                                                   +                           \+/ 
 *                                                  o|o                       --+-:-+--
 *                                                +--o--+                        /+\ 
 *         Liebe Grüße Johannes                     o|o                           |
 *         23.12.2014                                + 
 */  

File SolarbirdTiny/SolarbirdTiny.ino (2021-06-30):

// nick@bitfasching.de, Kazoosh, 2021
// For ATtiny85 @ 8 MHz


// I/O pins //

#define PIN_PIEZO_A 3
#define PIN_PIEZO_B 4
#define PIN_LED_1_ANODE 0
#define PIN_LED_2_ANODE 1
#define PIN_LED_CATHODES 2


// High-level access to I/O and system features //

#include "system/leds.h"
#include "system/piezo.h"
#include "system/lowpower.h"


// Bird voice //

#include "voices/blackbird.h"
Blackbird Bird;


// Behaviour settings //

const bool runStartupTest = false;
const bool powerDownAfterStartIfDark = false;
const unsigned long powerDownAfterStartIfDarkTimeoutMillis = 5*1000;
const bool lightLEDsWhenPlaying = true;
const int activityMaximum = 8; // should be divisible by the difference of activeSoundInterval*
const int activeSoundIntervalMinimum = 1;
const int activeSoundIntervalMaximum = 5; // should be a power of 2 greater than the minimum
const int idleSoundIntervalMinimum = 60*10; // all intervals must be smaller than 32768
const int idleSoundIntervalMaximum = 60*60;
const int nightModeSleepSeconds = 2;
const bool silentAtNight = false;


// Main logic //

void setup()
{
	// wait to make sure programmer is high-Z
	// and be gentle with the power source
	delay( 100 );

	if ( runStartupTest )
	{
		// startup test: flash LEDs
		LEDs::on();
		delay( 50 );
		LEDs::off();
		delay( 500 );

		// startup test: play all melodies once with fixed delay in between
		for ( int i = 0; i < Bird.numMelodies; i++ ) {
			Bird.playSingleMelody( i, lightLEDsWhenPlaying );
			delay( 1000 );
		}

		delay( 1000 );
	}

	if ( powerDownAfterStartIfDark )
	{
		// check if environment is not dark
		bool dark = true;
		unsigned long startTime = millis();
		while ( millis()-startTime <= powerDownAfterStartIfDarkTimeoutMillis ) {
			if ( LEDs::senseRawBrightness( false ) > 0 ) {
				dark = false;
				break;
			}
		}
		if ( dark ) {
			// no brightness sensed within defined time window, power down and don't wake up until external reset
			Piezo::on();
			Piezo::tone( 1E6/220, 1E6 );
			Piezo::off();
			LowPower::powerDown();
		}
	}

	// initialize random number generator with external source of randomness
	pinMode( PIN_LED_1_ANODE, INPUT ); pinMode( PIN_LED_2_ANODE, INPUT );
	randomSeed( analogRead( PIN_LED_1_ANODE ) ^ analogRead( PIN_LED_2_ANODE ) );
}

void loop()
{
	static int lastBrightness = 0;
	static int activity = 0;
	static bool active = false;
	static int cyclesBeforeNextSound = 0;

	// measure current brightness (logarithmic value, proportional to order of magnitude)
	int brightness = LEDs::senseBrightness();

	// determine if in darkness (i.e., night mode)
	bool dark = lastBrightness == 0 && brightness == 0;

	// compare with previous brightness (don't care for sign) and save for next cycle
	int brightnessActivity = abs( lastBrightness - brightness );
	lastBrightness = brightness;

	// accumulate activity within limit
	activity = activity + brightnessActivity;
	activity = min( activityMaximum, activity );

	// true if just became active in current cycle
	bool justBecameActive = false;

	// sensed activity?
	if ( activity > 0 )
	{
		// flash LEDs, the more activity the longer
		LEDs::on();
		delay( activity * 2 );
		LEDs::off();

		// just became active?
		if ( !active )
		{
			// set flag and remember active state
			justBecameActive = true;
			active = true;
		}
	}
	else
	{
		// clear active state
		active = false;
	}

	// time to make noise?
	// either after scheduled interval or on transition from idle to active
	if ( cyclesBeforeNextSound == 0 || justBecameActive )
	{
		// play sound
		Bird.play( lightLEDsWhenPlaying );

		// determine waiting time before next sound (both for active and idle case)
		if ( activity > 0 )
		{
			// active case = mapping of max activity to min interval plus one cycle of randomness
			cyclesBeforeNextSound = (activityMaximum-activity) * (activeSoundIntervalMaximum-activeSoundIntervalMinimum) / activityMaximum + activeSoundIntervalMinimum + random( 0, 1+1 );
		}
		else
		{
			cyclesBeforeNextSound = random( idleSoundIntervalMinimum, idleSoundIntervalMaximum+1 );
		}
	}
	else
	{
		// stop counter when in night mode, i.e., remain silent at night
		if ( !dark || !silentAtNight ) {
			cyclesBeforeNextSound--;
		}
	}

	// decrease activity level
	if ( activity > 0 ) { activity--; }

	// wait 1 second by day (2 seconds by night) until next cycle
	LowPower::sleepSeconds( dark && !active ? nightModeSleepSeconds : 1 );
}

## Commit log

2021-03-12 add files to material
2021-03-16 ade circuits
2021-03-30 add pcp files
    [Solaranimal210328.kicad_pcb, Solaranimal210328.sch, Solaranimal210329_1422.kicad_pcb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]
2021-03-30 remove files from pcb
    [Solaranimal210328.kicad_pcb, Solaranimal210328.sch, Solaranimal210329_1422.kicad_pcb]
2021-03-30 change pcb to new version
    [Solaranimal210330_1217.csv, Solaranimal210330_1217.kicad_pcb, Solaranimal210330_1217.sch]
2021-03-30 add .lib files for pcb
2021-03-30 add datasheed to GN LED
    [Solaranimal210330_1217.kicad_pcb]
2021-03-31 minor changes
    [Solaranimal210330_1217.kicad_pcb]
2021-04-01 change Q2
    [Solaranimal210330_1217.kicad_pcb, Solaranimal210330_1217.sch]
2021-04-01 add adc appnotes
2021-04-26 new version with LFSR Noise
    [main.c]
2021-04-26 better LFSR PowerMixer
2021-05-02 Add first draft of Arduino program with chirp-based bird voice
2021-05-02 Add instructions for flashing the Arduino program
2021-05-09 README: Clarify that flashing instructions refer to using Arduino IDE
2021-05-09 Bugfix: New melody index would not update if actually different than previous
    [SolarbirdTiny.ino]
2021-05-09 Integrate LEDs, add deterministic startup test routine
2021-05-09 Change delay between melodies of a series from variable to short fixed
    [SolarbirdTiny.ino]
2021-05-09 LEDs: Completely avoid digitalWrite, disconnect on switching off
2021-05-09 Move LED flashing on play to Blackbird::playSingleMelody() and make it optional
2021-05-09 Implement low-power sleep
2021-05-13 add glow LEDs
2021-05-16 Softer startup to avoid overloading the fragile power supply
    [SolarbirdTiny.ino]
2021-05-16 LEDs: Light refactoring
2021-05-17 LEDs: Add draft of brightness sensing (however unsatisfying, takes too long in darkness)
2021-05-17 LEDs: Improve brightness sensing (limited sensing of dark conditions, better sensitivity in bright conditions)
2021-05-18 LEDs: Refactor sensing function and fix bug (complement at the end unnecessary, already counting backwards)
2021-05-18 Move computation of log brightness to leds.h
2021-05-18 change directory names and add more datasheeds
    [Solaranimal210330_1217.csv, Solaranimal210330_1217.kicad_pcb, Solaranimal210330_1217.sch]
2021-05-19 LEDs: Sacrifice some accuracy when sensing and avoid disabling interrupts to keep timers running
2021-05-19 LEDs: Make disabling interrupts when sensing a function argument
2021-05-19 Add startup routine to permanently power down when in darkness
2021-05-19 Increase timeout before powering down when starting in darkness
2021-05-31 add circuit folder
    [Solaranimal210527_2049.sch]
2021-06-02 Improved power supply allows to disable power down on startup and to decrease sleep interval in darkness
2021-06-02 change circuit
2021-06-28 Extend piezo chirp function to support different tone period update intervals - needed for slow chirps at high frequencies - also disable interrupts by default to avoid glitches in tone generation
